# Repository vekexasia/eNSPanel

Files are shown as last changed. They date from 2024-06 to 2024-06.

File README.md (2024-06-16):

# eNSPanel

The Sonoff NSPanel US is a good looking touch panel that can be used to control your smart home devices. 

It features:

- a capacitive display,
- 2 physical buttons,
- a buzzer,
- 2 relays,
- WiFi & BT via esp32.
- No more issues in flashing the display

The original firmware did not fit my needs so I decided to create a custom firmware for it using ESPHome. How to do that is out of the scope of this repository.

## Why a new PCB?

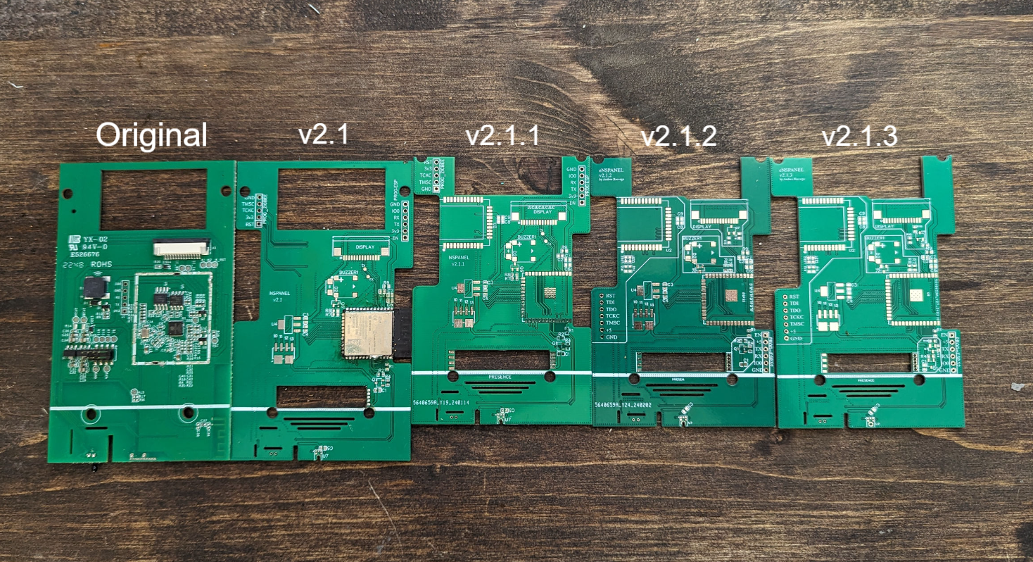
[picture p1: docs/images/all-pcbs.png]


The original PCB is great but I wanted to add some to add a few features:

- LD2410 presence detection sensor
- microphone for voice commands `*`
- ~ZigBee router*~ (removed in v2.1.4)
- an upgraded ESP32 module (ESP32-S3-WROOM-1-N16R8)

`*` Requires an S3 module with PSRAM (Ex: ESP32-S3-WROOM-1-N16R)

All of these features are optional and can be omitted if you don't need them.

Also, since many manifacturing companies **provide a big discount for PCBs that are 100x100mm or smaller**, I decided to make the PCB fit that dimensions.

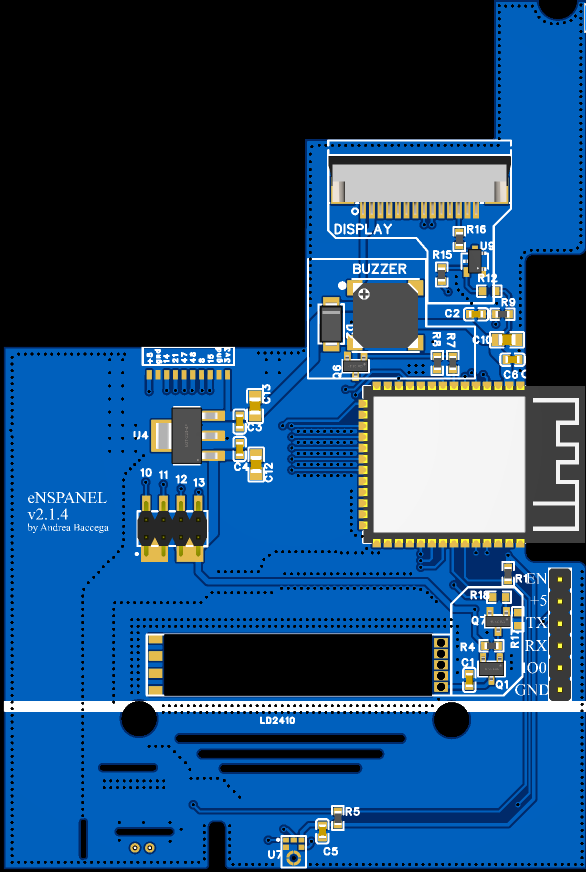
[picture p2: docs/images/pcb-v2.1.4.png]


## I want it... tell me more!

The documentation is quite extensive and can be found in the **[website](https://enspanel-docs.andreabaccega.com/)**.

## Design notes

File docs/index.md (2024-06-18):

# Welcome to eNSPanel

For full documentation visit [here](https://enspanel-docs.andreabaccega.com/).

## Features

- [LD2410](modules/presence.md) presence sensor
- Low cost PCB production (dimensions <100x100mm)
- [Microphone](modules/microphone.md) for voice assistant
- [mother-daughter](daughter.md) pcb (to extend functionalities)
- enclosure compatibility `*`
- all the goodies from the NSPanel such as:
  1. capacitive display
  2. buzzer 
  3. 2 relays
  4. ...

`*` only if not slotting the LD2410. otherwise a 3d printed part is required.

## Why?

The NSPanel from SonOff is a great device. I have 8 in my home serving as thermostats and doing much more. Unfortunately their outdated hardware is quite limiting. 

For example one of the reason why the ESPHome version struggles in **uploading the TFT** to the Nextion panel is the lack of free memory.

Another reason why the NSPanel needed an upgrade was/is the **lack of other functionalities.** With edge AI and [wake-word recognition](microwakeword.md) inside the ESP32-S3 module you could really have a **smart voice assistant in each room** (like I have in my case).

Initially I also wanted to slot a ZigBee module that could also enhance my home ZigBee network but starting from v1.4 I decided that [mother-daughter](daughter.md) approach was the best to minimize costs and reduce waste.

For example one could design a daughter board with a small speaker to engage with the voice assistant... Want an **atmospheric sensor?** design a board for it. Not happy with the AI capabilities of the slotted ESP32-S3? you get the idea :)

## How?

Since the replacement board needed to be compatible with the original board, a 1:1 SVG has been created with relevant holes and dimentions.  

Reference SVG

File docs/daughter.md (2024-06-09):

# Daughter Boards

The first big noticeable difference between the original PCB and the new one is the presence of a daughter board. The idea behind this is to have a main PCB that can be used for different purposes. For example, you could design a daughter board with a ZigBee module, or a daughter board with a speaker, or a daughter board with a sensor. The possibilities are endless.

The main PCB has 6 GPIOs that can be used to communicate with the daughter board. The daughter board can be powered by the main PCB... Both +5V and +3.3V are available on the daughter board.

Daughter/mother connection can be done via the [BC075-10-A-L-A](https://www.mouser.it/ProductDetail/GCT/BC075-10-A-L-A?qs=KUoIvG%2F9IlYLBy0sutz%2FEA%3D%3D) connector (if soldered) or wires could be hand-soldered to the 1mm pitch pads on the main PCB.

For example, you could design a daughter board with a ZigBee module, or a daughter board with a speaker, or a daughter board with a sensor. The possibilities are endless.

The main PCB has 6 GPIOs that can be used to communicate with the daughter board. 

## Connector

Daughter/mother connection can be done via the [BC075-10-A-L-A](https://www.mouser.it/ProductDetail/GCT/BC075-10-A-L-A?qs=KUoIvG%2F9IlYLBy0sutz%2FEA%3D%3D) connector (if soldered) or wires could be hand-soldered to the 1mm pitch pads on the main PCB.

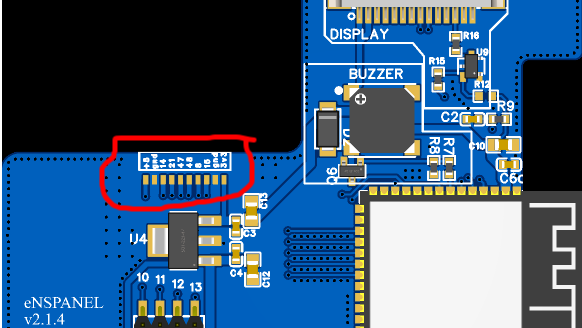
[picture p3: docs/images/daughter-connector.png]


From left to right here the 10 pins:

1. +5V
2. GND
3. IO14
4. IO21
5. IO47
6. IO48
7. IO8
8. IO16
9. GND
10. 3.3V

## Designing a Daughter Board

The daughter board can be designed in any way you like. But there are dimension constraints.

Constraints:

- max 34.6x51.4mm
- max 1.6mm thickness
- 1mm pitch for the connector
- at least 16.51 mm clearance from first connector pad to the edge of the board
- at least 8.5 mm clearance from the last connector pad to the edge of the board

All measurements are shown below:
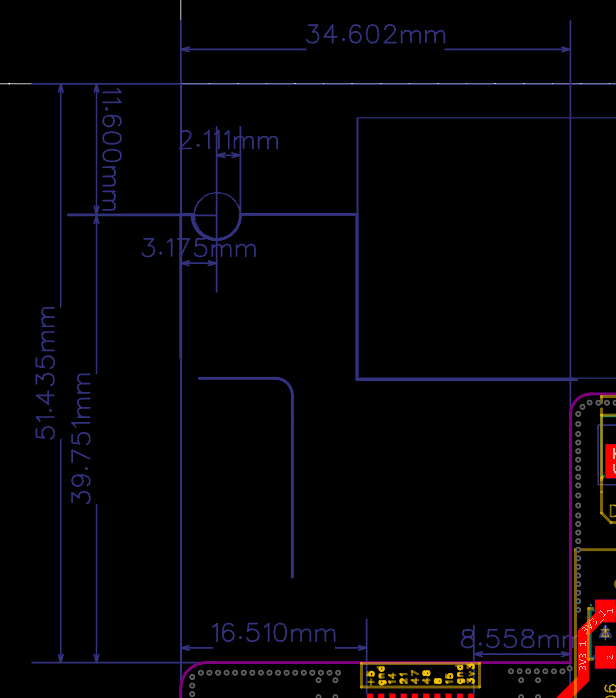
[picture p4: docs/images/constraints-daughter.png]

 
**NOTE**: Please **mind the hole** in the daughter board. The hole is there to allow the daughter board to be slotted in the enclosure. The hole is 2.1mm in radius and is centered at ~3.2mm from left edge and 11.6mm from the top edge.

**NOTE**: Having some clearance is always a good idea.

Also, in case you need to slot an **antenna**, please **use the leftmost edge of the daughter board**!

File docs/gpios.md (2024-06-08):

Here a GPIO table for the ESP32 module used in the PCB:

| GPIO | Function | Description |
|---|---|---|
| 3 | Thermistor VCC | Switch to provide NTC thermistor VCC only when measuring |
| 4 | Display | Display power on/off |
| 5 | Display RX | Display UART data line |
| 6 | Display TX | Display UART data line |
| 7 | Buzzer | Buzzer PWM |
| 8 | Daughter | |
| 9 | Thermistor ADC | Measurement PIN for the Thermistor |
| 10 | Header | wired but not used |
| 11 | Relay | Relay #1 |
| 12 | Relay | Relay #2 |
| 13 | Header | wired but not used |
| 14 | Daughter | |
| 15 | Daughter | |
| 16 | LD2410 | Presence sensor power cutoff |
| 17 | LD2410 | Presence sensor RX |
| 18 | LD2410 | Presence sensor TX |
| 35 | Microphone | i2c mic WS |
| 36 | Microphone | i2c mic SD |
| 37 | Microphone | i2c mic SCK |
| 38 | Microphone | i2c mic SCK |
| 41 | Switch | right switch |
| 42 | Switch | left switch |
| 21 | Daughter | |
| 47 | Daughter | |
| 48 | Daughter | |

Basically all the useable GPIOs are being used. Some of them are being allocated for the daughter board. And 2 of them for the 2.0mm pitch header.

Here below a pinout reference taken from [`atomic14`'s repository](https://github.com/atomic14/esp32-s3-pinouts)

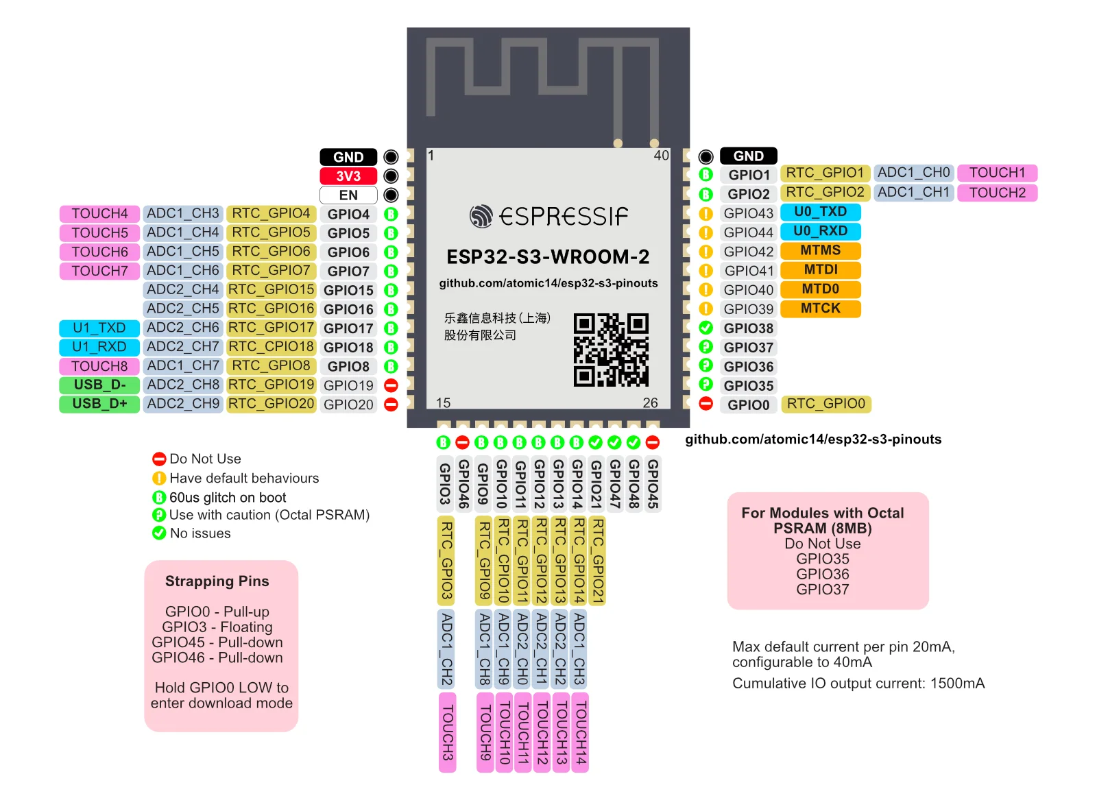
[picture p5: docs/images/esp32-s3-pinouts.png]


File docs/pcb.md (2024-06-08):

# PCB

The PCB can be ordered at any pcb manifacturing website that supports the Gerber format. The Gerber files are in the `gerber` folder.
Since v2.1 the PCB is <100x100mm this will allow for a big discount when ordering.

## How to order?

Simply download the `gerber.zip` file from the `gerber` folder and upload it to your favorite PCB manifacturer.

Another possibility would be using this [PCBWay shared project](https://www.pcbway.com/project/shareproject/eNSPanel_v2_1_4_f0fd8d8d.html). Be aware that the assembly and BOM in the project page has never been tested.

## PCB Settings

Besides the standard settings, I'd recommend to use HASL lead-free.

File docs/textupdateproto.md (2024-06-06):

## The problem

My specific setup is a Home Assistant integration with ESPHome.

The Nextion firmware has more than 15 text elements that rely on home assistant for their content.

The "original" way of updating the text elements is to use the `text_sensor` component in ESPHome and update the text elements in the Nextion firmware using the `on_value` trigger.

But this approach **requires a `text_sensor` per component** hence the code becomes a mess really fast...

The solution involves 2 parts:

- **Home Assistant side**: a text sensor that holds all the text elements in a single string
- **ESPHome side**: a script that parses the string and updates the text elements in the Nextion display

It's important to note that this approach **can be used standalone** and there is nothing in this project that relies on this approach/protocol.

I just found it useful for my specific use case. So documenting it here sounds like a good idea.

## The protocol

To fix my issue I had to invent a text format that could be easily parsed by the ESPHome script(see below) and HomeAssistant printable.

One caveat I found is that text sensor in Home Assistant does not support states longer than 255 characters. So I used an attribute instead.

The text format is as follows:

```
$page.$componentName,$value|
$page.$componentName,$value|
|
```

- `$page`: is the page name in the Nextion display. If the page is the same for all the components you can omit it.
- `$componentName`: is the component name in the Nextion display
- `$value`: is the value to be set in the text component

Between each component there is a `|\n` separator. The end is marked by a `|` character.

## EspHome side

```yaml
script:
  - id: restore_nspanel_texts
    then:
      - lambda: |-
          std::string main = id(nspanel_texts).state;   
          std::string md = "| ";   

          size_t pos = 0;   
          int index = 0;   
          while ((pos = main.find(md)) != std::string::npos) {   
            std::string s = main.substr(0, pos);   
            main.erase(0, pos + md.length());  
            std::string delimiter = ",";   
            std::string key = s.substr(0, s.find(delimiter));   
            std::string value = s.substr(key.length() + 1, s.rfind(delimiter) - key.length()  - 1); 
            id(disp1).set_component_text_printf(key.c_str(), "%s", value.c_str());
          }

text_sensor:
  - platform: homeassistant
    id: nspanel_texts
    entity_id: sensor.nspanel_texts
    attribute: value
    on_value:
      then:
        - script.execute: restore_nspanel_texts

```

## Home Assistant side

Home assistant side obviously depends on your personal setup both in HA and Nextion.

Anyways here is a simple example of how to create such sensor.

```yaml
template:
  - sensor:
    - name: "NSPanel Texts"
      state: >-
        {{ now().strftime('%d-%m-%Y %H:%M:%S') }}
      attributes:
        value: >-
          weather_now.temp_out,{{states('sensor.nspanel_outside_temp')}}|
          weather_now.humidity_out,{{states('sensor.nspanel_outside_humidity')}}|
          weather_now.wind_speed,{{states('sensor.nspanel_outside_windspeed')}}|
          weather_now.sunset,{{states('sensor.nspanel_next_sunset')}}|
          weather_now.sunrise,{{states('sensor.nspanel_next_sunrise')}}|
          |
```

This is a simple example of how to update the weather information in the Nextion display updating the `weather_now` page components.

## Caveats

As already said a Home Assistant attribute must be used because the state is limited to 255 characters. Also, keep in mind that **nextion components should be marked as `global`**.

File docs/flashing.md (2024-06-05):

# Flashing

After [slotting](soldering.md) the ESP32 along with the first required components, you **do not need to solder the header**. Actually it's not a good idea also because the display will not fit anymore and desoldering it is a pain..

I would recommend to either use some pogo pin clips like [this one](https://aliexpress.com/item/1005004869027755.html), or just press fit the pins keeping them in place.

After the first flashing, the other components can be soldered in any order.

## Flashing the Firmware

Besides the hardware connection you need to either use the [esphome cli](https://esphome.io/guides/getting_started_command_line.html) or the [web esphome](https://web.esphome.io/) flasher using a USB-TTL adapter.

To enter bootloader mode you need to connect the `EN` and `IO0` pins to ground. Specifically I find that a good way to to it is following the sequence below:

- Connect your adapter to the header provided
- Connect the `EN` pin to ground
- Connect the `IO0` pin to ground
- Remove the `EN` pin from ground
- Remove the `IO0` pin from ground

**PROTIP**: The ESP32 metal case is GND.

## The First Firmware
As per the first firmware the following should just work out of the box.

```yaml
esphome:
  name: sample-esp32
  friendly_name: sample-esp32
  platformio_options:
    board_build.flash_mode: dio
esp32:
  board: esp32-s3-devkitc-1
  framework:
    type: esp-idf

psram:
  mode: octal
  speed: 80MHz

# Enable logging
logger:
  hardware_uart: UART0
  level: DEBUG

# Enable Home Assistant API
api:
  # Once onboarded into HA u can remove this
  reboot_timeout: 0s
  encryption:
    key: "redacted"

ota:
  password: "redacted"

wifi:
  ssid: !secret wifi_ssid
  password: !secret wifi_password
  # had issues with output_power not being specified
  output_power: 12dB
```

Flashing the previous bare minimum firmware should be straightforward. If you have any issues please refer to the [ESPHome documentation](https://esphome.io/guides/getting_started_command_line.html).

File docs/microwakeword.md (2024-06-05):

Since ESPHome supports on-device wake word detection, it is possible to use the wake word detection to trigger a voice assistant. This is a sample configuration that uses the wake word detection to trigger a voice assistant.

Considering the chosen module (ESP32-S3-WROOM-1-N16R8) has PSRAM, the eNSPanel is fully capable to perform on-device wake word detection.

After properly configuring the [microphone](modules/microphone.md), the following configuration can be used to trigger a voice assistant.

```yaml
esphome:
  on_boot:
    priority: -100
    then:
      - micro_wake_word.start:
external_components:
  - source: github://pr#5230
    components: esp_adf
    refresh: 0s
micro_wake_word:
  microphone: mic
  model: hey_jarvis
  on_wake_word_detected:
    - rtttl.play: 'beep:d=16,o=5,b=100:e6'
    - wait_until:
        not:
          rtttl.is_playing:
    - voice_assistant.start:
voice_assistant:
  on_client_connected:
    - micro_wake_word.start:
  on_client_disconnected:
    - micro_wake_word.stop:
  on_error:
    then:
      - rtttl.play: 'beep:d=16,o=5,b=100:e6'
  on_end:
    then:
      - wait_until:
          not:
            voice_assistant.is_running:
      - micro_wake_word.start:  
```

For debug purposes, once recognized, the buzzer will play a beep and the voice assistant will start.

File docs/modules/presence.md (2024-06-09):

The LD2410 is a very well known and relatively inexpensive presence sensor.

Its speed, angle and capabilities make it a very versatile sensor. The main drawback is that it cannot be battery powered.
 
Thankfully we can power it via the main PCB. The sensor can be soldered on the main PCB. 

## GPIOs

The LD2410 is wired to the ESP32 using **GPIO17(RX) and GPIO18(TX)**. Furthermore, GPIO16 can be used to cut power to the module.

## Configuration

The most recent configuration yaml can be found in the `esphome` folder inside the repository. A known working configuration is the following:

```yaml

# Configuration for LD2410 presence sencor.
# The sensor needs to be actively powered on to work. that is why GPIO16 is used for.
switch:
  - platform: gpio
    name: LD2410 Power
    id: ld2410_power
    pin:
      number: 16
      inverted: false
    restore_mode: ALWAYS_OFF

uart:
  - tx_pin: 17
    rx_pin: 18
    baud_rate: 256000
    parity: NONE
    stop_bits: 1
    id: ld2410_uart

ld2410:
  uart_id: ld2410_uart

binary_sensor:
  - platform: ld2410
    has_target:
      name: Presence
    has_moving_target:
      name: Moving Target
    has_still_target:
      name: Still Target

sensor:
  - platform: ld2410
    moving_distance:
      name : Moving Distance
    still_distance:
      name: Still Distance
    moving_energy:
      name: Move Energy
    still_energy:
      name: Still Energy
    detection_distance:
      name: Detection Distance

```

## Drawbacks of slotting the LD2410

Unfortunately due to the size of the sensor and its high frequency of operation, the sensor could not be placed in a more convenient location.

Furthermore, due to height limitations in the current enclosure, you will need to print a 3d part to replace the original one.

The 3D part can be found in the `3d` folder. This is the only replacement part needed to slot the LD2410 sensor.

## LD2410 sensor soldering

Several iterations of the PCB were done to try to slot the LD2410 sensor without the need to change anything about the enclosure. Unfortunately, the sensor is too big to fit in the enclosure.

The best compromise was to have the sensor laying on top of the PCB. This way there is a semi-easy way to solder the LD2410 sensor.

To do that:

1. place the sensor on the PCB.
2. fill the pins with solder paste,
3. use your hot air gun.

### Testing with a multimeter

After soldering the sensor, it's a good idea to test it with a multimeter.

Testing continuity between the pins should give you a good idea if the sensor is soldered correctly. Just check out the following image.
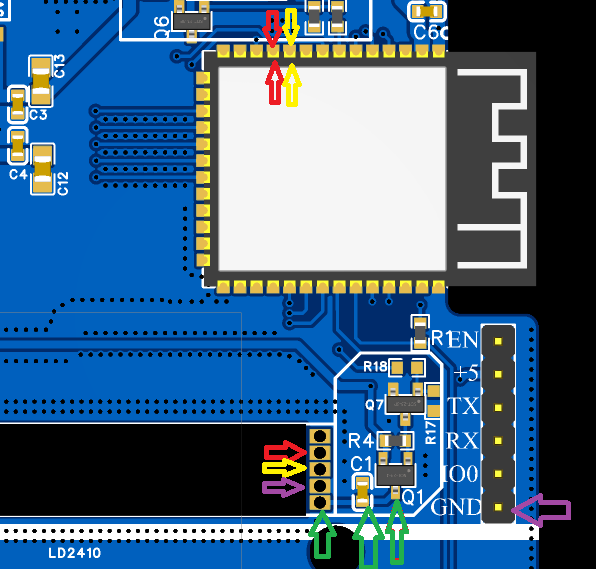
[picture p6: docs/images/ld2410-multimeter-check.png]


**If you don't find continuity across the marked locations, then the sensor is not soldered correctly.**

## Accuracy behind the enclosure

The sensor is very accurate and can detect presence from a good distance.
For sure there is a tradeoff when using the sensor behind a plastic enclosure. The sensor is not as accurate as it would be if it was placed in an open space. But in my **non scientific** tests, the sensor does still serve its purpose.

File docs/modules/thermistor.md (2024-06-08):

Much like the original PCB, eNSPanel uses an NTC thermistor to measure ambient temperature.

The thermistor is connected to the ESP32 via a voltage divider. The voltage divider is made up of a 20k resistor and the thermistor. The voltage divider is connected to the ESP32's ADC pin.

The thermistor is a normal 10k NTC thermistor with a B value of 3950. There is another 10k resistor in series with the thermistor to protect the ESP32's ADC pin.

## GPIO

The thermistor is connected to the ESP32 via `IO9` which is ADC1 in the selected ESP32 module.

## Configuration

The most up-to-date configuration is in the `esphome` folder. This is a known to be working minimal configuration for the thermistor:

```yaml
sensor:
  # Internal temperature sensor, adc value
  - platform: adc
    id: ntc_source
    pin: 9
    attenuation: auto

  # Internal temperature sensor, adc reading converted to resistance (calculation)
  - platform: resistance
    id: resistance_sensor
    sensor: ntc_source
    configuration: UPSTREAM
    resistor: 10kOhm

  # Internal temperature sensor, resistance to temperature (calculation)
  - platform: ntc
    id: temperature
    sensor: resistance_sensor
    calibration:
      b_constant: 3950
      reference_temperature: 25°C
      reference_resistance: 10kOhm
    name: Temperature

switch:
  - platform: gpio
    pin: 3
    id: ntc_vcc
interval:
  - interval: 10s
    then:
      - switch.turn_on: ntc_vcc
      - delay: 100ms
      - component.update: ntc_source
      - switch.turn_off: ntc_vcc
```

Also the ESPHome platform provides a [climate component](https://esphome.io/components/climate/index.html) that can be used to control a heater or a cooler. The climate component can be used to control a relay that turns on a heater or a cooler. Check the [relays](relays.md) documentation for more info.

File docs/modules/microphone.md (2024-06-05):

The microphone is one of the new features included in the eNSPanel PCB. 

I decided to slot a microphone cause I wanted to have a device in each room capable of recognizing a wake word.

## GPIO

The microphone needs to be a footprint compatible (see part below) i2c microphone. the following ESP32 pins were used:

- GPIO38 - lrclk
- GPIO40 - bclk
- GPIO39 - din

## Configuration

Always refer to the `esphome` folder for the most up to date working configuration. This is a known to be working minimal configuration for the microphone

```yaml

i2s_audio:
  i2s_lrclk_pin: GPIO38
  i2s_bclk_pin: GPIO40
microphone:
  - platform: i2s_audio
    id: mic
    adc_type: external
    i2s_din_pin: GPIO39
    pdm: false
    channel: left
voice_assistant:
  microphone: mic
  auto_gain: 31dBFS
#  noise_suppression_level: 2
```

## Part

`ICS-43434` microphone was used and known to be working with the PCB.

## Soldering

Soldering such mics require some patience. A good solder paste does wonders.

What I usually do is:

- Solder all the components and keep the mic as last 
- Apply solder paste (Better with a stencil)
- use hot air gun
- gently apply some force on top,
- test...

In case it does not work I desolder with the hot air gun and repeat.

## Related Parts

Only C5 (top layer) and R3 (bottom layer) are needed to make the microphone to work. 

## Testing the mic

Sometimes it might be a pain to test a working microphone. To date I don't know any method more effective than installing the voice assist package and try to speak the wake word.

Aka. You should really check out the [voice assistant](../microwakeword.md) section of this documentation

### Debugging poor audio quality

Most of the times if u hear statics or other jibberish it means the microphone is not properly soldered onto the board.

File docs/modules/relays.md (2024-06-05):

Much like the original PCB, eNSPanel supports the original 2 Relays.

Furthermore, even if there is no use for them right now, there are 2 other GPIO pins that can be used in the future in case there will ever a need for a new pcb for the power supply module.
## GPIO

The 2 relays are connected to the ESP32 via `IO11` and `IO12`.

## Configuration

The most up-to-date configuration is in the `esphome` folder. This is a known to be working minimal configuration for the 2 relays:

```yaml
switch:
  # Physical relay 1
  - platform: gpio
    name: Relay 1
    id: relay_1
    pin:
      number: 11
  # Physical relay 2
  - platform: gpio
    name: Relay 2
    id: relay_2
    pin:
      number: 12
```

# Climate configuration

As explained in the [thermistor](thermistor.md) documentation, the ESPHome platform provides a [climate component](https://esphome.io/components/climate/index.html) that can be used to control a heater or a cooler. The climate component can be used to control a relay that turns on a heater or a cooler. 

The following is a sample configuration to leverage one of the relay to control a heater:

```yaml
climate:
  - platform: thermostat
    id: termostato
    name: "Termostat"
    sensor: temperature
    min_heating_off_time: 60s
    min_heating_run_time: 60s
    min_idle_time: 30s
    heat_action:
      - switch.turn_on: relay_1
    idle_action:
      - switch.turn_off: relay_1
    default_preset: Home
    preset:
      - name: Home
        default_target_temperature_low: $target_temp_home
        mode: HEAT
      - name: Comfort
        default_target_temperature_low: $target_temp_comfort
        mode: HEAT
```

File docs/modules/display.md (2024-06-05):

The capacitive Nextion display is what makes the NSPanel a good Home automation product.

## GPIO

In the original board the nextion display communicates with the esp32 via `IO16` & `IO17`. In the new board the display communicates with the esp32 via `IO5` & `IO6`, they are not hardware UART but that was already allocated to the presence sensor which has a higher baudrate.

## Configuration

Always refer to the `esphome` folder for the most up to date working configuration. This is a known to be working minimal configuration for the display

```yaml

uart:
  - tx_pin: 5
    rx_pin: 6
    baud_rate: 115200
    rx_buffer_size: 4096
    id: tf_uart

display:
  - platform: nextion
    id: disp1
    uart_id: tf_uart
    tft_url: $tft_url

switch:
  - platform: gpio
    name: Screen Power
    id: screen_power
    entity_category: config
    pin:
      number: 4
      inverted: true
    restore_mode: ALWAYS_OFF
```

Please note that the `tft_url` should be the path to the compiled tft file. The `tft` file is the compiled version of the `HMI` file that is generated by the [Nextion Editor](https://nextion.tech/nextion-editor/).

Also note that there are other configuration elements that make the display work as expected. Please refer to the `esphome` folder for the most up to date configuration.

## Part

There are several parts that are required for the display to work. The parts are all contained in the `DISPLAY` silkscreen polygon.

## Display Firmware

The nextion display can be updated via the `UART` interface. The display firmware is included in this repository. With the original NSPanel hardware, uploading a new `tft` file to the display was a pain.
With the new board, thanks to the more generous availability of memory, uploading a new `tft` file is a breeze.

The firmware for the display is included in this repository and can be found in the `nextion` folder. Wish you modify the display firmware, you can use the [Nextion Editor](https://nextion.tech/nextion-editor/) generate the `HMI` file (or modify the provided one) and then compile it to a `tft` file.

### Getting ready to flash the display firmware

To flash the display firmware you need to have the following:

- a working `http` server that can serve the `tft` file
- a working `esphome` firmware that can communicate with the display
- a HomeAssistant service that can trigger the display firmware update

#### 1) The webserver

as of the http server I suggest you to spin up a simple `nginx` server that serves the `tft` file. 

The following Nginx configuration should work:

```nginx
server {
    listen 80;
    root /var/www/html;
}
```
Just place the tft file in the `/var/www/html` folder and you should be good to go.

Also, using something like [filebrowser](https://github.com/filebrowser/filebrowser) should make the process easier to manage firmware files.

#### 2) The `esphome` firmware

The esphome configuration is provided in the `esphome/nextion.yaml` file. 

To summarize you need to have at least the `uart`, the `display` and the `api` component for the next step

#### 3) The HomeAssistant service

The HomeAssistant service is provided in the `esphome/nextion.yaml` file.

But you can also use the following service:

```yaml

api:
  services:
    - service: upload_tft
      then:
        - lambda: 'id(disp1)->upload_tft();'

```

The $tft_url should be provided as part of the yaml esphome configuration. (check `esphome/vekexasia-hmi.yaml` for an example)

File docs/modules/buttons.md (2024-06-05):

Much like the original PCB, eNSPanel is slotting 2 microswitches to make a use of the 2 physical buttons.

## GPIO

The 2 microswitches are connected to the ESP32 via `IO42`(left) and `IO41`(right).

## Configuration

The most up-to-date configuration is in the `esphome` folder. This is a known to be working minimal configuration for the thermistor:

```yaml
binary_sensor:
  # Left button below the display
  - platform: gpio
    name: $friendly_devicename Left Button
    pin:
      number: GPIO42
      inverted: true
    id: left_button

  # Right button below the display
  - platform: gpio
    name: $friendly_devicename Right Button
    pin:
      number: GPIO41
      inverted: true
    id: right_button

```

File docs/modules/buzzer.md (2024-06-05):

Both the original PCB and all the eNSPanel PCBs slot a buzzer.

The buzzer could be used as a feedback after user's action or to play tones/notify important messages.

## GPIO

The buzzer is connected to the ESP32 via **GPIO7**

## Configuration

Always refer to the `esphome` folder for the most up to date working configuration. This is a known to be working minimal configuration for the buzzer

```yaml

rtttl:
  id: buzzer
  output: buzzer_out

output:
  - platform: ledc
    id: buzzer_out
    pin:
      number: 7
```

## Part

Almost any `SMD,7.5x7.5mm` buzzer with an operating voltage of 3v3 should be working. For my boards I went with `MLT-7525`

## Soldering

Soldering the buzzer and the related parts (see below) should be pretty straightforward. Just mind both **the buzzer and the diode polarity**.
## Related Parts

All the parts related to the buzzer are containerd inside the silkscreen polygon marked as `BUZZER`.

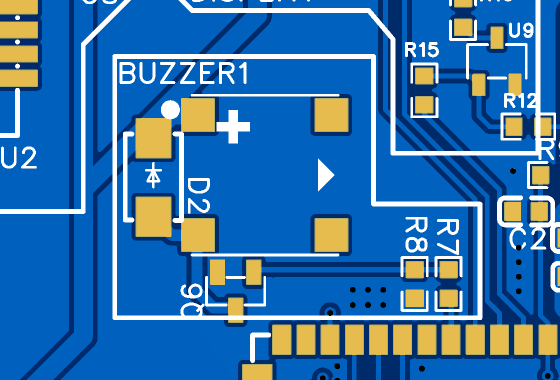
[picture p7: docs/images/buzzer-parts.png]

 
Wish you to not slot the buzzer for whatever reason you can skip soldering all the components included in that region.

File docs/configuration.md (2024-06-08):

ESPHome configuration can be found in the `esphome` folder inside the repository. 

Also minimal configuration for specific modules can be found in the respective module pages. For example, the [microphone](modules/microphone.md) and the [presence sensor](modules/presence.md) have their own configuration snippets.

## vekexasia-hmi.yaml

You can check the `vekexasia-hmi.yaml` file for a way to use the other modules yaml files.

Keep in mind that the `vekexasia-hmi.yaml` file is a way to combine all the modules into one yaml file. It is not a requirement to use it.

Also, this configuration might not work out of the box as it might be missing some other configuration elements that I regularly use.

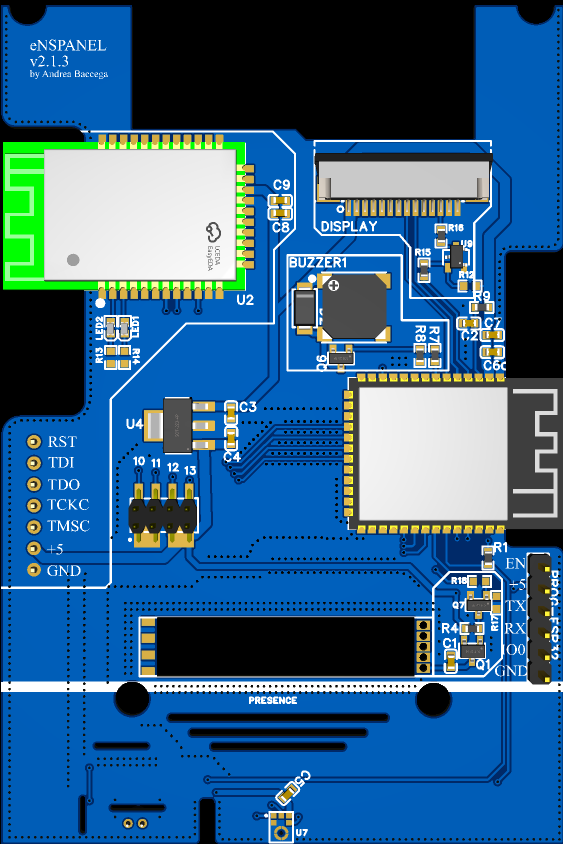
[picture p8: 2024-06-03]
docs/v1.3.png

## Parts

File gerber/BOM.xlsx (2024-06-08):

No. | Quantity | Comment | Designator | Footprint | Value | Manufacturer Part | Manufacturer | Supplier Part | Supplier
1 | 1 | 2700Hz | BUZZER | BUZ-SMD_4P-L7.5-W7.5-P7.59-TL |  | MLT-7525 | 华能 | C95299 | LCSC
2 | 4 | 100nF | C1,C2,C5,C6 | C0603 |  | CL10B104KO8NNNC | SAMSUNG(三星) | C66501 | LCSC
3 | 2 | 10uF | C3,C4 | C0603 |  | CL10A106MO8NQNC | SAMSUNG(三星) | C92487 | LCSC
4 | 3 | 22uF | C10,C12,C13 | C0805 | 22uF | CL21A226MOQNNNE | SAMSUNG(三星) | C98190 | LCSC
5 | 1 | 1N4001_C2909965 | D2 | SMA_L4.2-W2.6-LS5.0-RD |  | 1N4001 | YONGYUTAI(永裕泰) | C2909965 | LCSC
6 | 1 | AFA07-S14FCC-00 | DISPLAY | FPC-SMD_P1.00-14P_LCS-XJ-H2.5 |  | AFA07-S14FCC-00 | JS(钜硕电子) | C262348 | LCSC
7 | 1 | Molex 87759-7648 | H1 | HDR-SMD_8P-P2.00-V-M-R2-C4-S2.0 |  | 87759-7648 | Molex | 538-87759-7648 | Mouser
8 | 1 | HLK-LD2410B-P | LD2410 | newld2410 |  | HLK-LD2410B-P | HI-LINK(海凌科) | C5183132 | LCSC
9 | 1 | Header-Male-2.54_1x6 | PROG-ESP32 | hdr-th_6p-p2.54-v-m-1 |  | 2.54-1x6P直针 | BOOMELE(博穆精密) | C37208 | LCSC
10 | 1 | FDN304P | Q1 | SOT-23-3_L2.9-W1.6-P1.90-LS2.8-BR |  | FDN304P | onsemi(安森美) | C241803 | LCSC
11 | 2 | FDV305N | Q6,Q7 | SOT-23-3_L2.9-W1.3-P1.90-LS2.4-BR |  | FDV305N | onsemi(安森美) | C154511 | LCSC
12 | 8 | 10kΩ | R1,R4,R5,R8,R9,R12,R17,R20 | R0603 |  | TC0325D1002T5E | UNI-ROYAL(厚声) | C425463 | LCSC
13 | 1 | 100kΩ | R3 | R0603 |  | TC0325D1003T5E | UNI-ROYAL(厚声) | C415143 | LCSC
14 | 2 | 100Ω | R7,R18 | R0603 |  | TC0325D1000T5E | UNI-ROYAL(厚声) | C25201 | LCSC
15 | 1 | 120Ω | R15 | R0603 | 120Ω | 0603WAJ0121T5E | UNI-ROYAL(厚声) | C25205 | LCSC
16 | 1 | 470Ω | R16 | R0603 | 470Ω | 0603WAF4700T5E | UNI-ROYAL(厚声) | C23179 | LCSC
17 | 2 | TS-1101-C-W | SW1,SW2 | SW-SMD_L6.0-W3.3-LS8.0 |  | TS-1101-C-W | XKB Connectivity(中国星坤) | C318938 | LCSC
18 | 1 | MF52 | THERMISTOR | RES-TH_L2.5-W2.5-P1.70-D0.3 |  | MF52A103F3950 (A1) | 时恒 | C13879 | LCSC
19 | 1 | BL8071CLATR33 | U4 | SOT-223-3_L6.5-W3.4-P2.30-LS7.0-BR |  | BL8071CLATR33 | BL(上海贝岭) | C401677 | LCSC
20 | 1 | ICS-43434 | U7 | ics-43434 |  | ICS-43434 | null | C9900000518 | LCSC
21 | 1 | ESP32-S3-WROOM-1-N16R8 | U8 | wirelm-smd_esp32-s3-wroom-1 |  | ESP32-S3-WROOM-1-N16R8 | ESPRESSIF(乐鑫) | C2913202 | LCSC
22 | 1 | S8050 | U9 | SOT-23-3_L2.9-W1.6-P1.90-LS2.8-BR |  | S8050 | KUU | C7603172 | LCSC
23 | 1 | bc075-10-a-l-a | U10 | bc075-10-A-L-A

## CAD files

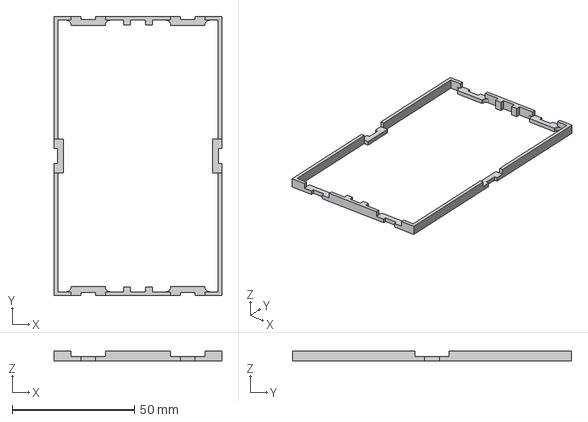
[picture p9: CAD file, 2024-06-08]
3d/eNSPanel v2.1.4 enclosure.step
68.8 x 114.4 x 4.20 mm

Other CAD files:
3d/eNSPanel v2.1.4 enclosure.f3d

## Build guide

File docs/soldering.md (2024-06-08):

# Soldering

First component that needs to be soldered is the **ESP32**. This makes the first flashing super easy.

## 1) ESP32 Soldering

A bare minimal component soldering includes:
- R9 (0603 10kΩ)
- C6, C2, C4, C3 (0603 100nF)
- C10, C12, C13 (0805 22uF)
- LDO (U4)

The components are circled here:

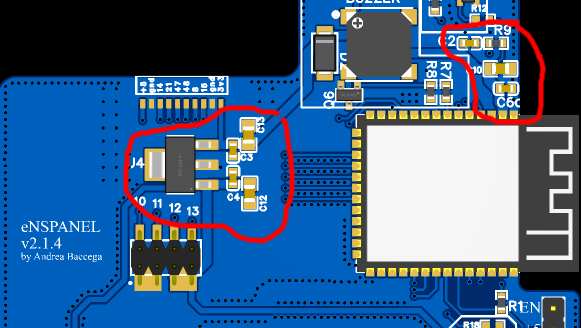
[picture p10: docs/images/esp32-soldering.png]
esp32-soldering

 
After soldering the ESP32, the LDO and the capacitors, the ESP32 can be flashed using the bottom right header. 

## 2) Other modules

The other modules can be soldered in any order. Just make sure to follow the schematic and the BOM.
I'd recommend to [flash first](flashing.md) the ESP32 and then solder the other components.

Some modules might be tricky to solder. For example, the [microphone](modules/microphone.md) and the [LD2410](modules/presence.md) might require some patience.

I'd solder the bottom layer components after first flashing the ESP32. This way you can test the ESP32 and the LDO.

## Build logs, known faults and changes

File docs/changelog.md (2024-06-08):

During the development and prototyping phase I designed different versions of the PCB.

This page is meant to be a changelog of the different versions of the PCB.

The current version is v2.1.4 which is the one supporting the [daughter board](daughter.md). Here below a picture of the v2.1.4 PCB:



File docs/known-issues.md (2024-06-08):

## Soldering

Most of the time soldering the right components properly is the key to a successful build. Check the [soldering](soldering.md) page for more info.

Especially the microphone and the LD2410 might be tricky to solder.

## Bootloop

It happened to me that the ESP32 went into a bootloop after being flashed with a minimal firmware.

I am not sure what caused it, but I suspect it was the `output_power` not being specified in the `wifi` section as adding it fixed the issue.

## Microphone not recognizing wake word

If the microphone is not recognizing the wake word, it might be due to the microphone not being properly soldered.

## LD2410 not working

If the LD2410 is not working, it might be due soldering issue. Check the soldering and the connections. The [presence sensor](modules/presence.md) page shows a diagram of the connections.

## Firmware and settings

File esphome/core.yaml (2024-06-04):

esphome:
  name: $device_name
  friendly_name: $friendly_devicename

mqtt:
  broker: !secret mqtt_ip
  username: !secret mqtt_username
  password: !secret mqtt_password
  discovery: false
  topic_prefix: "termostati/$device_name"
  log_topic: null
  
climate:
  - platform: thermostat
    id: termostato
    name: "Termostat"
    sensor: temperature
    min_heating_off_time: 60s
    min_heating_run_time: 60s
    min_idle_time: 30s
    heat_action:
      - switch.turn_on: relay_1
    idle_action:
      - switch.turn_off: relay_1
    default_preset: Home
    preset:
      - name: Home
        default_target_temperature_low: $target_temp_home
        mode: HEAT
      - name: Comfort
        default_target_temperature_low: $target_temp_comfort
        mode: HEAT
    on_state:
      - lambda: |-
          id(disp1).set_component_text_printf("home.set_temp", "%.1f °C", id(termostato).target_temperature);

binary_sensor:
  # Left button below the display
  - platform: gpio
    name: $friendly_devicename Left Button
    pin:
      number: GPIO42
      inverted: true
    id: left_button
    on_press:
      then:
        - switch.toggle: relay_1

  # Right button below the display
  - platform: gpio
    name: $friendly_devicename Right Button
    pin:
      number: GPIO41
      inverted: true
    id: right_button

sensor:
  # Internal temperature sensor, adc value
  - platform: adc
    id: ntc_source
    pin: 9
    update_interval: 10s
    attenuation: auto

  # Internal temperature sensor, adc reading converted to resistance (calculation)
  - platform: resistance
    id: resistance_sensor
    sensor: ntc_source
    configuration: UPSTREAM
    resistor: 20kOhm
    

  # Internal temperature sensor, resistance to temperature (calculation)
  - platform: ntc
    id: temperature
    sensor: resistance_sensor
    calibration:
      b_constant: 3950
      reference_temperature: 25°C
      reference_resistance: 20kOhm
    name: Temperature
    filters:
      - median:
          window_size: 10
          send_every: 5
          send_first_at: 5
    on_value:
      then:
        - lambda: |-
            float a = x;
            id(disp1).set_component_text_printf("home.temp_big", "%.1f", a);

switch:
  # Physical relay 1
  - platform: gpio
    name: Relay 1
    id: relay_1
    pin:
      number: 11

    on_turn_on:
      then:
        - script.execute: restore_relay_state_ui
    on_turn_off:
      then:
        - script.execute: restore_relay_state_ui
  # Physical relay 2
  - platform: gpio
    name: Relay 2
    id: relay_2
    pin:
      number: 12

  - platform: restart
    name: "Restart"

time:
  - platform: sntp
    id: sntp_time
    timezone: CET-1CEST,M3.5.0,M10.5.0/3
    on_time:
      - 
        seconds: 0
        minutes: /1
        then:
          - lambda: id(disp1).set_component_text_printf("home.time", "%02i:%02i", id(sntp_time).now().hour, id(sntp_time).now().minute);
    on_time_sync:
      then:
          - logger.log: 
              format: "Time sync %02i:%02i"
              args: [id(sntp_time).now().hour, id(sntp_time).now().minute]

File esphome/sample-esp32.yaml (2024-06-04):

esphome:
  name: sample-esp32
  friendly_name: sample-esp32
  platformio_options:
    board_build.flash_mode: dio
esp32:
  board: esp32-s3-devkitc-1
  framework:
    type: esp-idf

psram:
  mode: octal
  speed: 80MHz

# Enable logging
logger:
  hardware_uart: UART0
  level: DEBUG

# Enable Home Assistant API
api:
  #  reboot_timeout: 0s
  encryption:
    key: "redacted"

ota:
  password: "redacted"

wifi:
  ssid: !secret wifi_ssid
  password: !secret wifi_password
  # had issues with output_power not being specified
  output_power: 12dB

web_server:
  port: 80

packages:
  display: !include nextion.yaml
  hmi: !include vekexasia-hmi.yaml
  core: !include core.yaml
  ld: !include ld2410.yaml
  mic: !include microphone.yaml
  buzzer: !include buzzer.yaml
  microwakeword: !include test-microai.yaml

substitutions:
  device_name: sample-thermostat
  friendly_devicename: sample-thermosta
  tft_url: "http://filebrowser-iot.iot/nspanel/pre-babybuddy.tft"
  blank_tft_url: "http://filebrowser-iot.iot/nspanel/nspanel_blank.tft"
  target_temp_home: 19 °C
  target_temp_comfort: 20 °C

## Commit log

2024-06-04 add sample config
2024-06-04 :docs soldering
2024-06-05 :docs fixed some links and pcb page
2024-06-05 add gerber stuff
    [BOM.xlsx, pickandplace.xlsx]
2024-06-08 updated pcb fabrication files
    [BOM.xlsx, pickandplace.xlsx]
2024-06-08 add 3d stuff
    [eNSPanel v2.1.4 enclosure.f3d, eNSPanel v2.1.4 enclosure.step]
2024-06-09 :docs fixed link to daughter board connector and ld2040 clarification
